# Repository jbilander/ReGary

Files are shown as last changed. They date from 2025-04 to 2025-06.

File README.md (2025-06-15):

# Fat ReGary
A drop in replacement PCB for the Fat Gary chip 

This is WORK IN PROGRESS. If you generate gerbers and order PCBs from this source you are doing so completely at your own risk!.

***

<a href="images/ReGary_pic1.jpg">
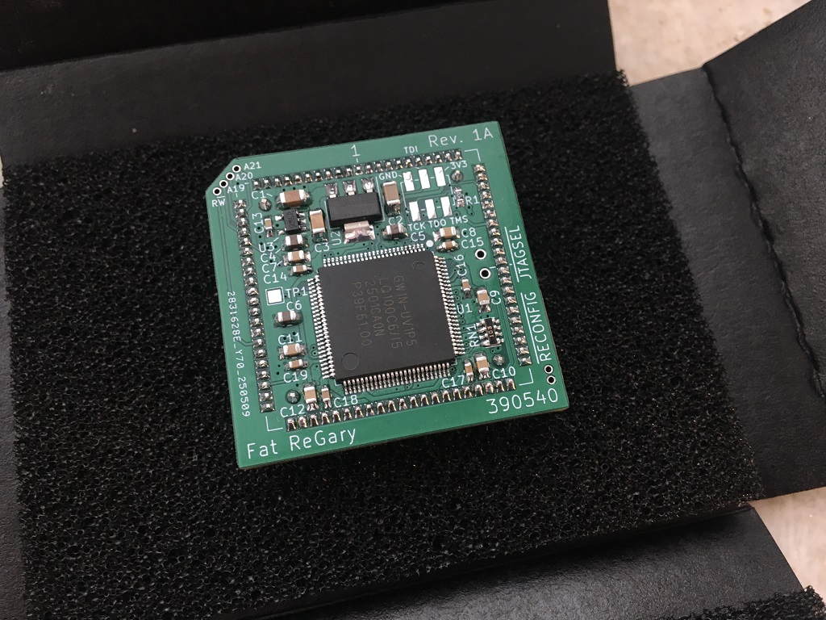
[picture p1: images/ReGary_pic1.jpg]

</a>
<a href="images/ReGary_pic2.jpg">
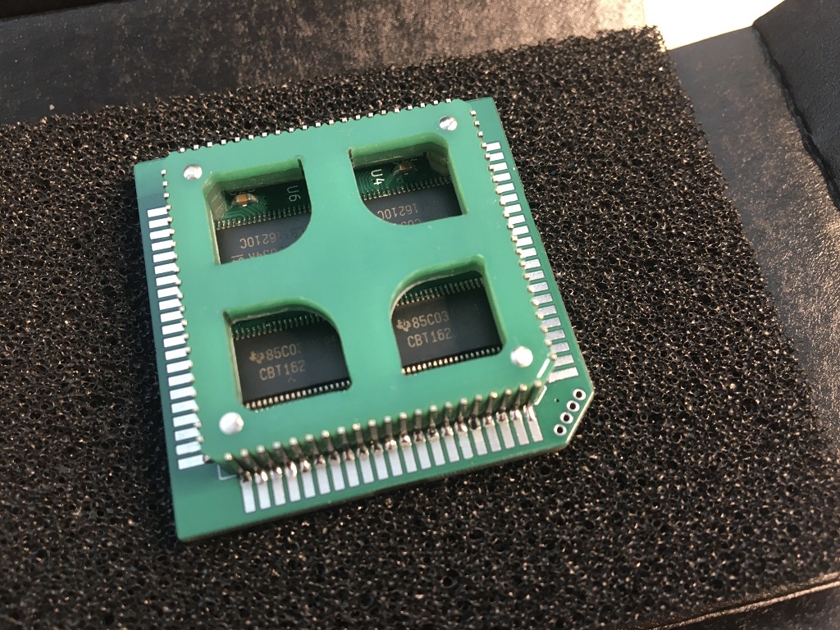
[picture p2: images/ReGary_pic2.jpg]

</a>
<a href="images/ReGary_pic3.jpg">
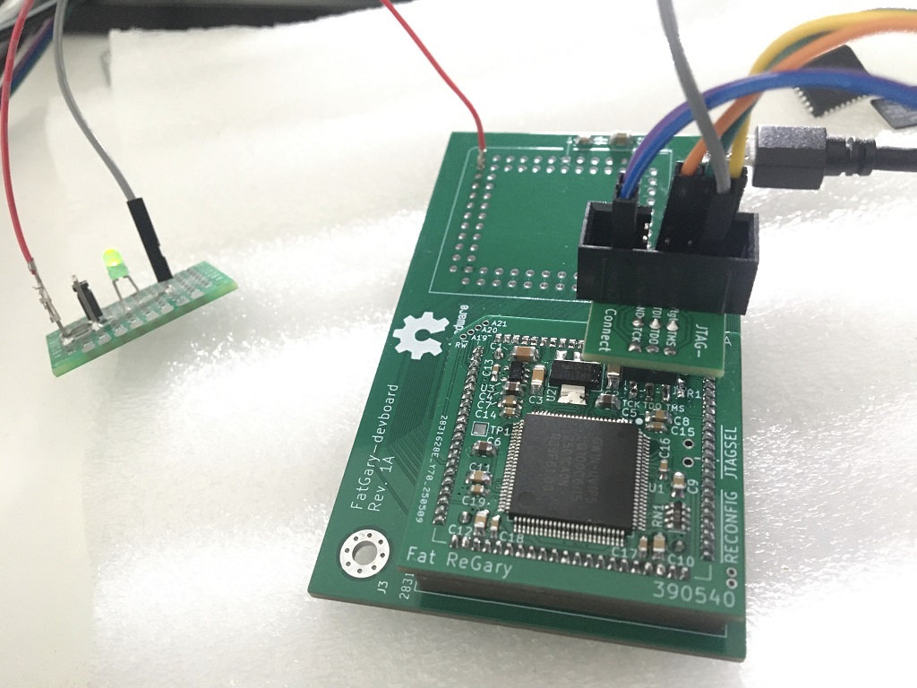
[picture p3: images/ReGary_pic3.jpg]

</a>

***

<a href="images/Fat_ReGary_pinmapping_rev1a.png">
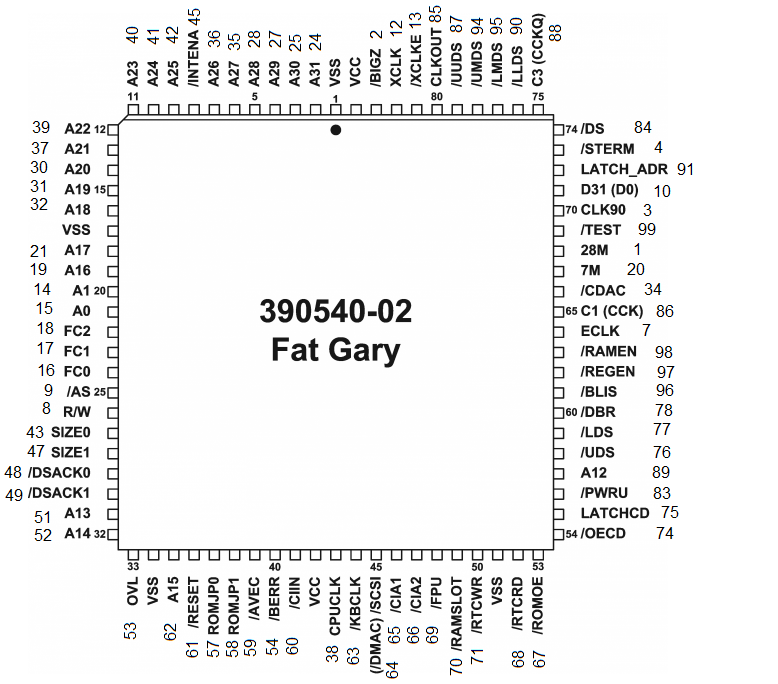
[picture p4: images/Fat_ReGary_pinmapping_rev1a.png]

</a>

***

BOM Rev. 1A
---------
Reference  | Name/Value   | Package | Notes
-|-|-|-|
U1 | GW1N-UV1P5LQ100  | TQFP-100_14x14mm_P0.5mm | Gowin FPGA [GW1N-UV1P5LQ100](https://www.mouser.com/ProductDetail/192-GW1P5LQ100C6-I5)
U2 | LM1117-3.3 | SOT-223 | Low-Dropout Linear Regulator 3.3 Volt
U3 | S-1132B43-M5T1U <br />or <br />TPS73643DBVR | SOT-23-5 | Low-Dropout Linear Regulator 4.3 Volt <br /> [S-1132B43-M5T1U](https://www.mouser.com/ProductDetail/628-S-1132B43-M5T1G) <br /> [TPS73643DBVR](https://www.mouser.com/ProductDetail/595-TPS73643DBVR) <br />
U4-U7 | SN74CBT16210 | TSSOP-48 6.1x12.5mm_P0.5mm | 20-BIT FET Bus switch with level shifting, high-speed TTL-compatible. [SN74CBT16210CDGGR ](https://www.mouser.com/ProductDetail/595-SN74CBT16210CDGG)
U8 | Winslow PLCC-84 Plug | PLCC-84 Plug | Optionally use a home made plug (stacked PCBs)
U9 | PLCC-84_TH_pin_holes | TH_plug_pins | Pins that could be used with the DIY-plug PCBs rev1d for manual fitting, L8.7mm [Aliexpress](https://www.aliexpress.com/item/32893608810.html).
R1 | 4.7k Ω | 0603 | Pull-down resistor for TCK (in JTAG)
RN1 | CAY16-103J4LF RES ARRAY 4 Resistors 10k Ω | 1206 | [CAY16-103J4LF](https://www.mouser.com/ProductDetail/652-CAY16-103J4LF)
C1-C3 | Capacitor 10uF | 1206 | 
C4-C6 | Capacitor 1uF | 0805 | 
C7-C12 | Capacitor 0.1uF = 100nF | 0805 | 
C13-C23 | Capacitor 0.01uF = 10nF | 0603 |
JTAG | SMT Pin Header Male | SMT 2 x 3 Pin 2.0mm pitch |

***

When ordering from JLCPCB select:

Specify Layer Sequence: Yes

    L1(Top layer):    F_Cu.gbr
    L2(Inner layer1): GND_Cu.gbr
    L3(Inner layer2): 4V3_Cu.gbr
    L4(Bottom layer): B_Cu.gbr

Remove Order Number: 

    Specify a location

This will notify JLC where to put the order number, they will replace the "JLCJLCJLCJLC" silkscreen label.

***

[][cc-by-sa]

This work is licensed under a
[Creative Commons Attribution-ShareAlike 4.0 International License][cc-by-sa].

[][cc-by-sa]

[cc-by-sa]: http://creativecommons.org/licenses/by-sa/4.0/
[cc-by-sa-image]: https://licensebuttons.net/l/by-sa/4.0/88x31.png
[cc-by-sa-shield]: https://img.shields.io/badge/License-CC%20BY--SA%204.0-lightgrey.svg

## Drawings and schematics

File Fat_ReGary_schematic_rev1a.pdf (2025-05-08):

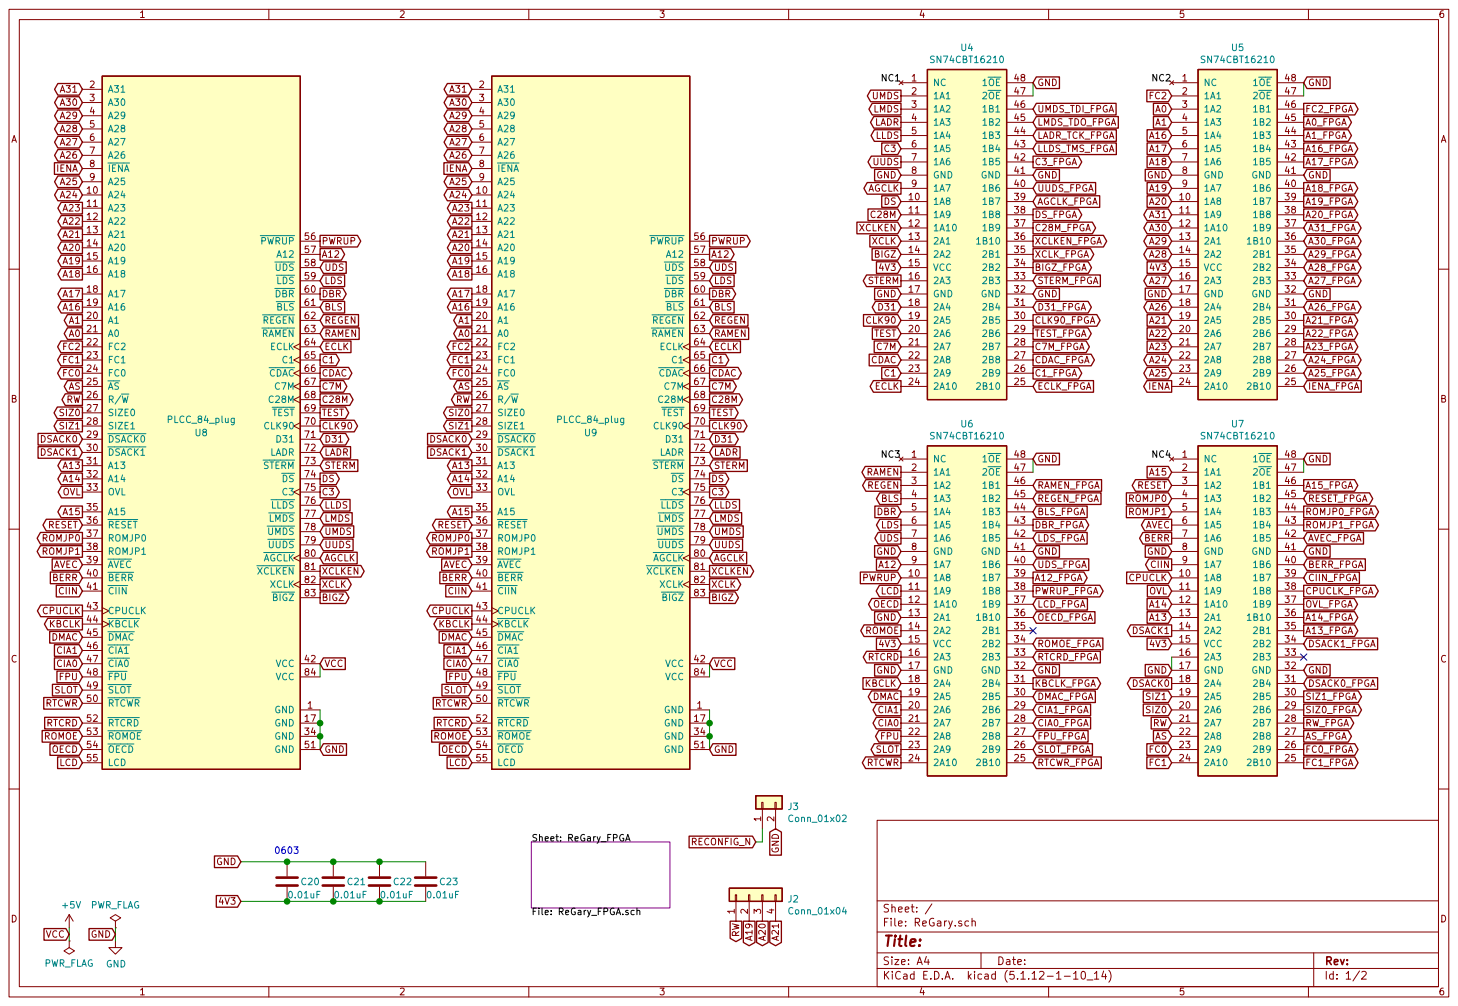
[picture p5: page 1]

File: ReGary.sch Sheet: / Sheet: ReGary_FPGA

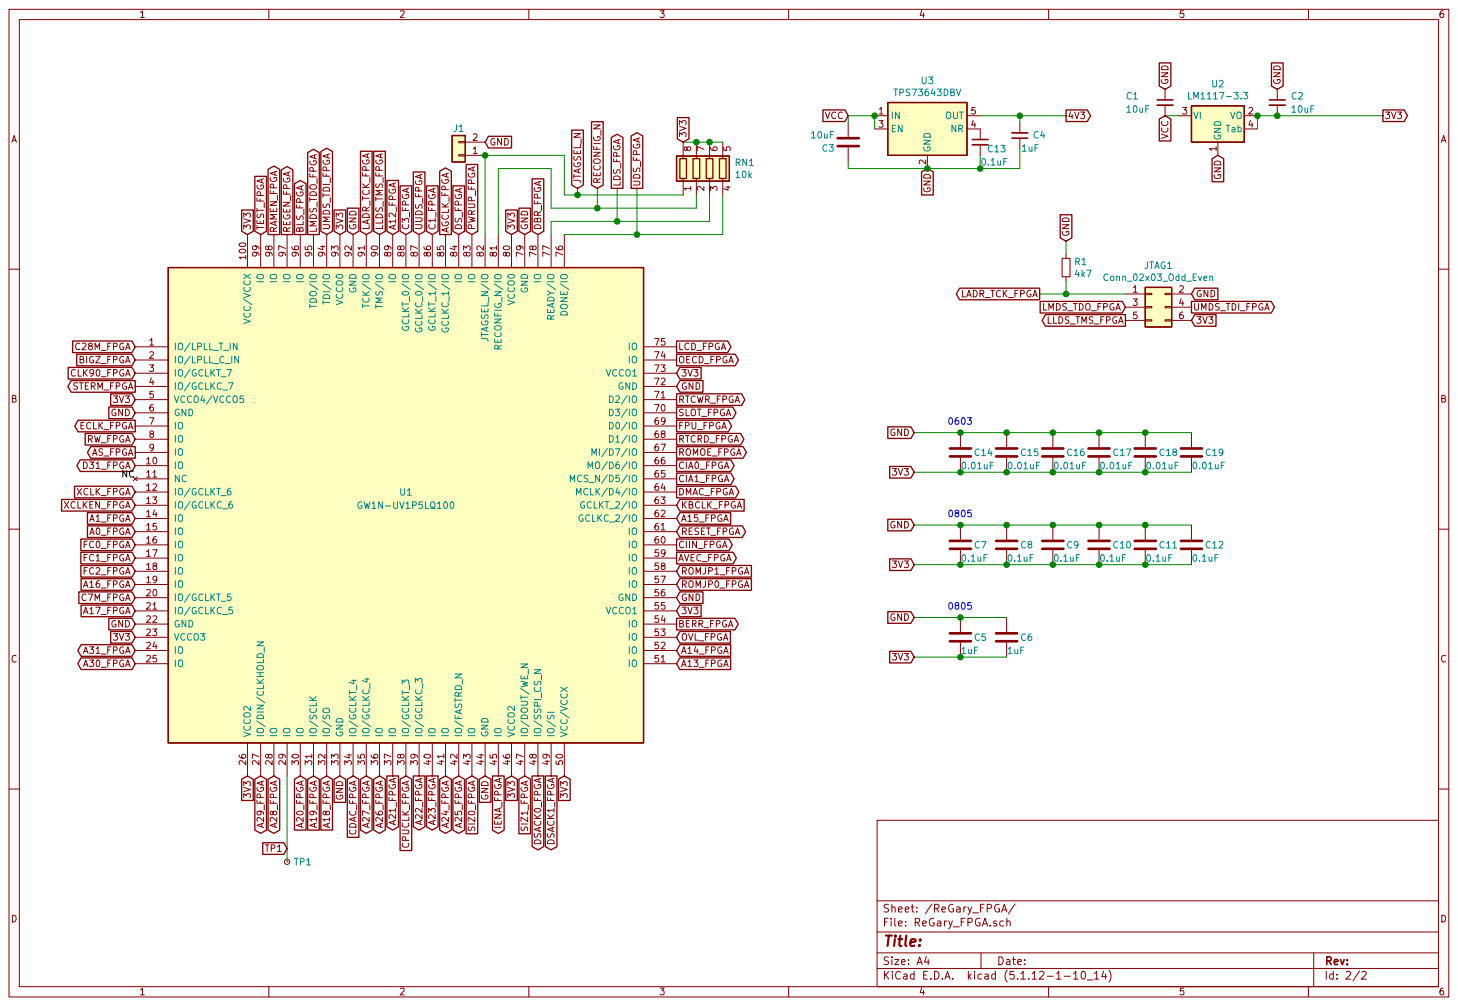
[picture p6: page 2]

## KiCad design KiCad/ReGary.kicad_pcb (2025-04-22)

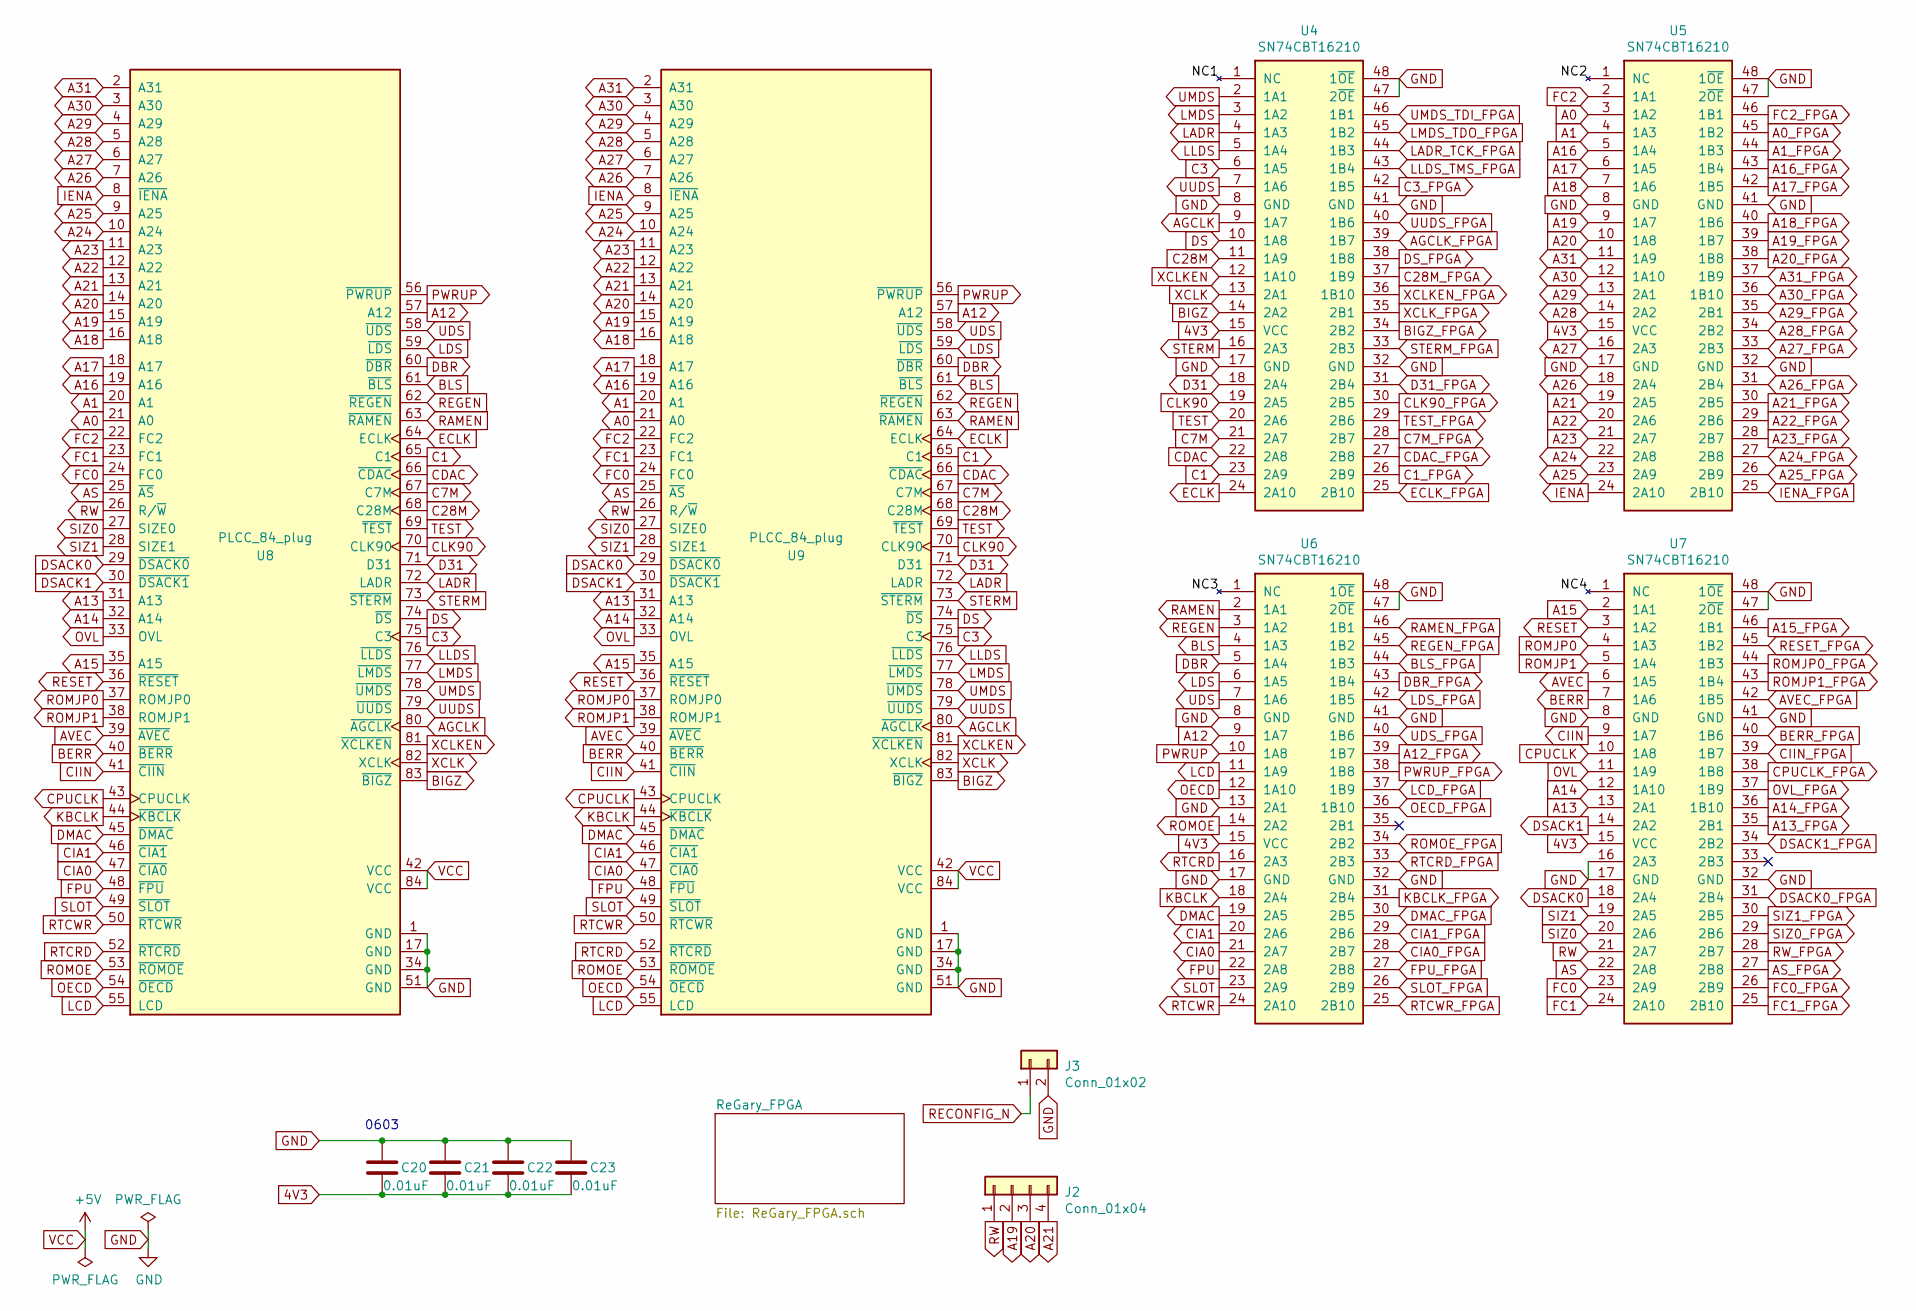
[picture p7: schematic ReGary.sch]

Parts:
C20, C21, C22, C23: 0.01uF; C_0603_1608Metric_Pad1.05x0.95mm_HandSolder
J2: Conn_01x04; PinHeader_1x04_P1.27mm_Vertical
J3: Conn_01x02; PinHeader_1x02_P1.27mm_Vertical
U4, U5, U6, U7: SN74CBT16210; TSSOP-48_6.1x12.5mm_P0.5mm_padLength_1mm
U8: PLCC_84_plug; PLCC-84_Plug_P1.27mm_mirrored
U9: PLCC_84_plug; PLCC-84_TH_pin_holes

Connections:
4V3: C20.2, C21.2, C22.2, C23.2, U4.15 (VCC), U5.15 (VCC), U6.15 (VCC), U7.15 (VCC); also elsewhere on the board
/NC1: U4.1 (NC)
/NC2: U5.1 (NC)
/NC3: U6.1 (NC)
/NC4: U7.1 (NC)
A0: U5.3 (1A2), U8.21 (A0), U9.21 (A0)
A0_FPGA: U5.45 (1B2); also elsewhere on the board
A1: U5.4 (1A3), U8.20 (A1), U9.20 (A1)
A1_FPGA: U5.44 (1B3); also elsewhere on the board
A12: U6.9 (1A7), U8.57 (A12), U9.57 (A12)
A12_FPGA: U6.39 (1B7); also elsewhere on the board
A13: U7.13 (2A1), U8.31 (A13), U9.31 (A13)
A13_FPGA: U7.35 (2B1); also elsewhere on the board
A14: U7.12 (1A10), U8.32 (A14), U9.32 (A14)
A14_FPGA: U7.36 (1B10); also elsewhere on the board
A15: U7.2 (1A1), U8.35 (A15), U9.35 (A15)
A15_FPGA: U7.46 (1B1); also elsewhere on the board
A16: U5.5 (1A4), U8.19 (A16), U9.19 (A16)
A16_FPGA: U5.43 (1B4); also elsewhere on the board
A17: U5.6 (1A5), U8.18 (A17), U9.18 (A17)
A17_FPGA: U5.42 (1B5); also elsewhere on the board
A18: U5.7 (1A6), U8.16 (A18), U9.16 (A18)
A18_FPGA: U5.40 (1B6); also elsewhere on the board
A19: J2.2, U5.9 (1A7), U8.15 (A19), U9.15 (A19)
A19_FPGA: U5.39 (1B7); also elsewhere on the board
A20: J2.3, U5.10 (1A8), U8.14 (A20), U9.14 (A20)
A20_FPGA: U5.38 (1B8); also elsewhere on the board
A21: J2.4, U5.19 (2A5), U8.13 (A21), U9.13 (A21)
A21_FPGA: U5.30 (2B5); also elsewhere on the board
A22: U5.20 (2A6), U8.12 (A22), U9.12 (A22)
A22_FPGA: U5.29 (2B6); also elsewhere on the board
A23: U5.21 (2A7), U8.11 (A23), U9.11 (A23)
A23_FPGA: U5.28 (2B7); also elsewhere on the board
A24: U5.22 (2A8), U8.10 (A24), U9.10 (A24)
A24_FPGA: U5.27 (2B8); also elsewhere on the board
A25: U5.23 (2A9), U8.9 (A25), U9.9 (A25)
A25_FPGA: U5.26 (2B9); also elsewhere on the board
A26: U5.18 (2A4), U8.7 (A26), U9.7 (A26)
A26_FPGA: U5.31 (2B4); also elsewhere on the board
A27: U5.16 (2A3), U8.6 (A27), U9.6 (A27)
A27_FPGA: U5.33 (2B3); also elsewhere on the board
A28: U5.14 (2A2), U8.5 (A28), U9.5 (A28)
A28_FPGA: U5.34 (2B2); also elsewhere on the board
A29: U5.13 (2A1), U8.4 (A29), U9.4 (A29)
A29_FPGA: U5.35 (2B1); also elsewhere on the board
A30: U5.12 (1A10), U8.3 (A30), U9.3 (A30)
A30_FPGA: U5.36 (1B10); also elsewhere on the board
A31: U5.11 (1A9), U8.2 (A31), U9.2 (A31)
A31_FPGA: U5.37 (1B9); also elsewhere on the board
AGCLK: U4.9 (1A7), U8.80 (~AGCLK), U9.80 (~AGCLK)
AGCLK_FPGA: U4.39 (1B7); also elsewhere on the board
AS: U7.22 (2A8), U8.25 (~AS), U9.25 (~AS)
AS_FPGA: U7.27 (2B8); also elsewhere on the board
AVEC: U7.6 (1A5), U8.39 (~AVEC), U9.39 (~AVEC)
AVEC_FPGA: U7.42 (1B5); also elsewhere on the board
BERR: U7.7 (1A6), U8.40 (~BERR), U9.40 (~BERR)
BERR_FPGA: U7.40 (1B6); also elsewhere on the board
BIGZ: U4.14 (2A2), U8.83 (~BIGZ), U9.83 (~BIGZ)
BIGZ_FPGA: U4.34 (2B2); also elsewhere on the board
BLS: U6.4 (1A3), U8.61 (~BLS), U9.61 (~BLS)
BLS_FPGA: U6.44 (1B3); also elsewhere on the board
C1: U4.23 (2A9), U8.65 (C1), U9.65 (C1)
C1_FPGA: U4.26 (2B9); also elsewhere on the board
C3: U4.6 (1A5), U8.75 (C3), U9.75 (C3)
C3_FPGA: U4.42 (1B5); also elsewhere on the board
C7M: U4.21 (2A7), U8.67 (C7M), U9.67 (C7M)
C7M_FPGA: U4.28 (2B7); also elsewhere on the board
C28M: U4.11 (1A9), U8.68 (C28M), U9.68 (C28M)
C28M_FPGA: U4.37 (1B9); also elsewhere on the board
CDAC: U4.22 (2A8), U8.66 (~CDAC), U9.66 (~CDAC)
CDAC_FPGA: U4.27 (2B8); also elsewhere on the board
CIA0: U6.21 (2A7), U8.47 (~CIA0), U9.47 (~CIA0)
CIA0_FPGA: U6.28 (2B7); also elsewhere on the board
CIA1: U6.20 (2A6), U8.46 (~CIA1), U9.46 (~CIA1)
CIA1_FPGA: U6.29 (2B6); also elsewhere on the board
CIIN: U7.9 (1A7), U8.41 (~CIIN), U9.41 (~CIIN)
CIIN_FPGA: U7.39 (1B7); also elsewhere on the board
CLK90: U4.19 (2A5), U8.70 (CLK90), U9.70 (CLK90)
CLK90_FPGA: U4.30 (2B5); also elsewhere on the board
CPUCLK: U7.10 (1A8), U8.43 (CPUCLK), U9.43 (CPUCLK)
CPUCLK_FPGA: U7.38 (1B8); also elsewhere on the board
D31: U4.18 (2A4), U8.71 (D31), U9.71 (D31)
D31_FPGA: U4.31 (2B4); also elsewhere on the board
DBR: U6.5 (1A4), U8.60 (~DBR), U9.60 (~DBR)
DBR_FPGA: U6.43 (1B4); also elsewhere on the board
DMAC: U6.19 (2A5), U8.45 (~DMAC), U9.45 (~DMAC)
DMAC_FPGA: U6.30 (2B5); also elsewhere on the board
DS: U4.10 (1A8), U8.74 (~DS), U9.74 (~DS)
DSACK0: U7.18 (2A4), U8.29 (~DSACK0), U9.29 (~DSACK0)
DSACK0_FPGA: U7.31 (2B4); also elsewhere on the board
DSACK1: U7.14 (2A2), U8.30 (~DSACK1), U9.30 (~DSACK1)
DSACK1_FPGA: U7.34 (2B2); also elsewhere on the board
DS_FPGA: U4.38 (1B8); also elsewhere on the board
ECLK: U4.24 (2A10), U8.64 (ECLK), U9.64 (ECLK)
ECLK_FPGA: U4.25 (2B10); also elsewhere on the board
FC0: U7.23 (2A9), U8.24 (FC0), U9.24 (FC0)
FC0_FPGA: U7.26 (2B9); also elsewhere on the board
FC1: U7.24 (2A10), U8.23 (FC1), U9.23 (FC1)
FC1_FPGA: U7.25 (2B10); also elsewhere on the board
FC2: U5.2 (1A1), U8.22 (FC2), U9.22 (FC2)
FC2_FPGA: U5.46 (1B1); also elsewhere on the board
FPU: U6.22 (2A8), U8.48 (~FPU), U9.48 (~FPU)
FPU_FPGA: U6.27 (2B8); also elsewhere on the board
GND: C20.1, C21.1, C22.1, C23.1, J3.2, U4.8 (GND), U4.17 (GND), U4.32 (GND), U4.41 (GND), U4.47 (2~OE), U4.48 (1~OE), U5.8 (GND), U5.17 (GND), U5.32 (GND), U5.41 (GND), U5.47 (2~OE), U5.48 (1~OE), U6.8 (GND), U6.13 (2A1), U6.17 (GND), U6.32 (GND), U6.41 (GND), U6.47 (2~OE), U6.48 (1~OE), U7.8 (GND), U7.16 (2A3), U7.17 (GND), U7.32 (GND), U7.41 (GND), U7.47 (2~OE), U7.48 (1~OE), U8.1 (GND), U8.17 (GND), U8.34 (GND), U8.51 (GND), U9.1 (GND), U9.17 (GND), U9.34 (GND), U9.51 (GND); also elsewhere on the board
IENA: U5.24 (2A10), U8.8 (~IENA), U9.8 (~IENA)
IENA_FPGA: U5.25 (2B10); also elsewhere on the board
KBCLK: U6.18 (2A4), U8.44 (~KBCLK), U9.44 (~KBCLK)
KBCLK_FPGA: U6.31 (2B4); also elsewhere on the board
LADR: U4.4 (1A3), U8.72 (LADR), U9.72 (LADR)
LADR_TCK_FPGA: U4.44 (1B3); also elsewhere on the board
LCD: U6.11 (1A9), U8.55 (LCD), U9.55 (LCD)
LCD_FPGA: U6.37 (1B9); also elsewhere on the board
LDS: U6.6 (1A5), U8.59 (~LDS), U9.59 (~LDS)
LDS_FPGA: U6.42 (1B5); also elsewhere on the board
LLDS: U4.5 (1A4), U8.76 (~LLDS), U9.76 (~LLDS)
LLDS_TMS_FPGA: U4.43 (1B4); also elsewhere on the board
LMDS: U4.3 (1A2), U8.77 (~LMDS), U9.77 (~LMDS)
LMDS_TDO_FPGA: U4.45 (1B2); also elsewhere on the board
OECD: U6.12 (1A10), U8.54 (~OECD), U9.54 (~OECD)
OECD_FPGA: U6.36 (1B10); also elsewhere on the board
OVL: U7.11 (1A9), U8.33 (OVL), U9.33 (OVL)
OVL_FPGA: U7.37 (1B9); also elsewhere on the board
PWRUP: U6.10 (1A8), U8.56 (~PWRUP), U9.56 (~PWRUP)
PWRUP_FPGA: U6.38 (1B8); also elsewhere on the board
RAMEN: U6.2 (1A1), U8.63 (~RAMEN), U9.63 (~RAMEN)
RAMEN_FPGA: U6.46 (1B1); also elsewhere on the board
RECONFIG_N: J3.1; also elsewhere on the board
REGEN: U6.3 (1A2), U8.62 (~REGEN), U9.62 (~REGEN)
REGEN_FPGA: U6.45 (1B2); also elsewhere on the board
RESET: U7.3 (1A2), U8.36 (~RESET), U9.36 (~RESET)
RESET_FPGA: U7.45 (1B2); also elsewhere on the board
ROMJP0: U7.4 (1A3), U8.37 (ROMJP0), U9.37 (ROMJP0)
ROMJP0_FPGA: U7.44 (1B3); also elsewhere on the board
ROMJP1: U7.5 (1A4), U8.38 (ROMJP1), U9.38 (ROMJP1)
ROMJP1_FPGA: U7.43 (1B4); also elsewhere on the board
ROMOE: U6.14 (2A2), U8.53 (~ROMOE), U9.53 (~ROMOE)
ROMOE_FPGA: U6.34 (2B2); also elsewhere on the board
RTCRD: U6.16 (2A3), U8.52 (~RTCRD), U9.52 (~RTCRD)
RTCRD_FPGA: U6.33 (2B3); also elsewhere on the board
RTCWR: U6.24 (2A10), U8.50 (~RTCWR), U9.50 (~RTCWR)
RTCWR_FPGA: U6.25 (2B10); also elsewhere on the board
RW: J2.1, U7.21 (2A7), U8.26 (R/~W), U9.26 (R/~W)
RW_FPGA: U7.28 (2B7); also elsewhere on the board
SIZ0: U7.20 (2A6), U8.27 (SIZE0), U9.27 (SIZE0)
SIZ0_FPGA: U7.29 (2B6); also elsewhere on the board
SIZ1: U7.19 (2A5), U8.28 (SIZE1), U9.28 (SIZE1)
SIZ1_FPGA: U7.30 (2B5); also elsewhere on the board
SLOT: U6.23 (2A9), U8.49 (~SLOT), U9.49 (~SLOT)
SLOT_FPGA: U6.26 (2B9); also elsewhere on the board
STERM: U4.16 (2A3), U8.73 (~STERM), U9.73 (~STERM)
STERM_FPGA: U4.33 (2B3); also elsewhere on the board
TEST: U4.20 (2A6), U8.69 (~TEST), U9.69 (~TEST)
TEST_FPGA: U4.29 (2B6); also elsewhere on the board
UDS: U6.7 (1A6), U8.58 (~UDS), U9.58 (~UDS)
UDS_FPGA: U6.40 (1B6); also elsewhere on the board
UMDS: U4.2 (1A1), U8.78 (~UMDS), U9.78 (~UMDS)
UMDS_TDI_FPGA: U4.46 (1B1); also elsewhere on the board
UUDS: U4.7 (1A6), U8.79 (~UUDS), U9.79 (~UUDS)
UUDS_FPGA: U4.40 (1B6); also elsewhere on the board
VCC: U8.42 (VCC), U8.84 (VCC), U9.42 (VCC), U9.84 (VCC); also elsewhere on the board
XCLK: U4.13 (2A1), U8.82 (XCLK), U9.82 (XCLK)
XCLKEN: U4.12 (1A10), U8.81 (~XCLKEN), U9.81 (~XCLKEN)
XCLKEN_FPGA: U4.36 (1B10); also elsewhere on the board
XCLK_FPGA: U4.35 (2B1); also elsewhere on the board

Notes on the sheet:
0603

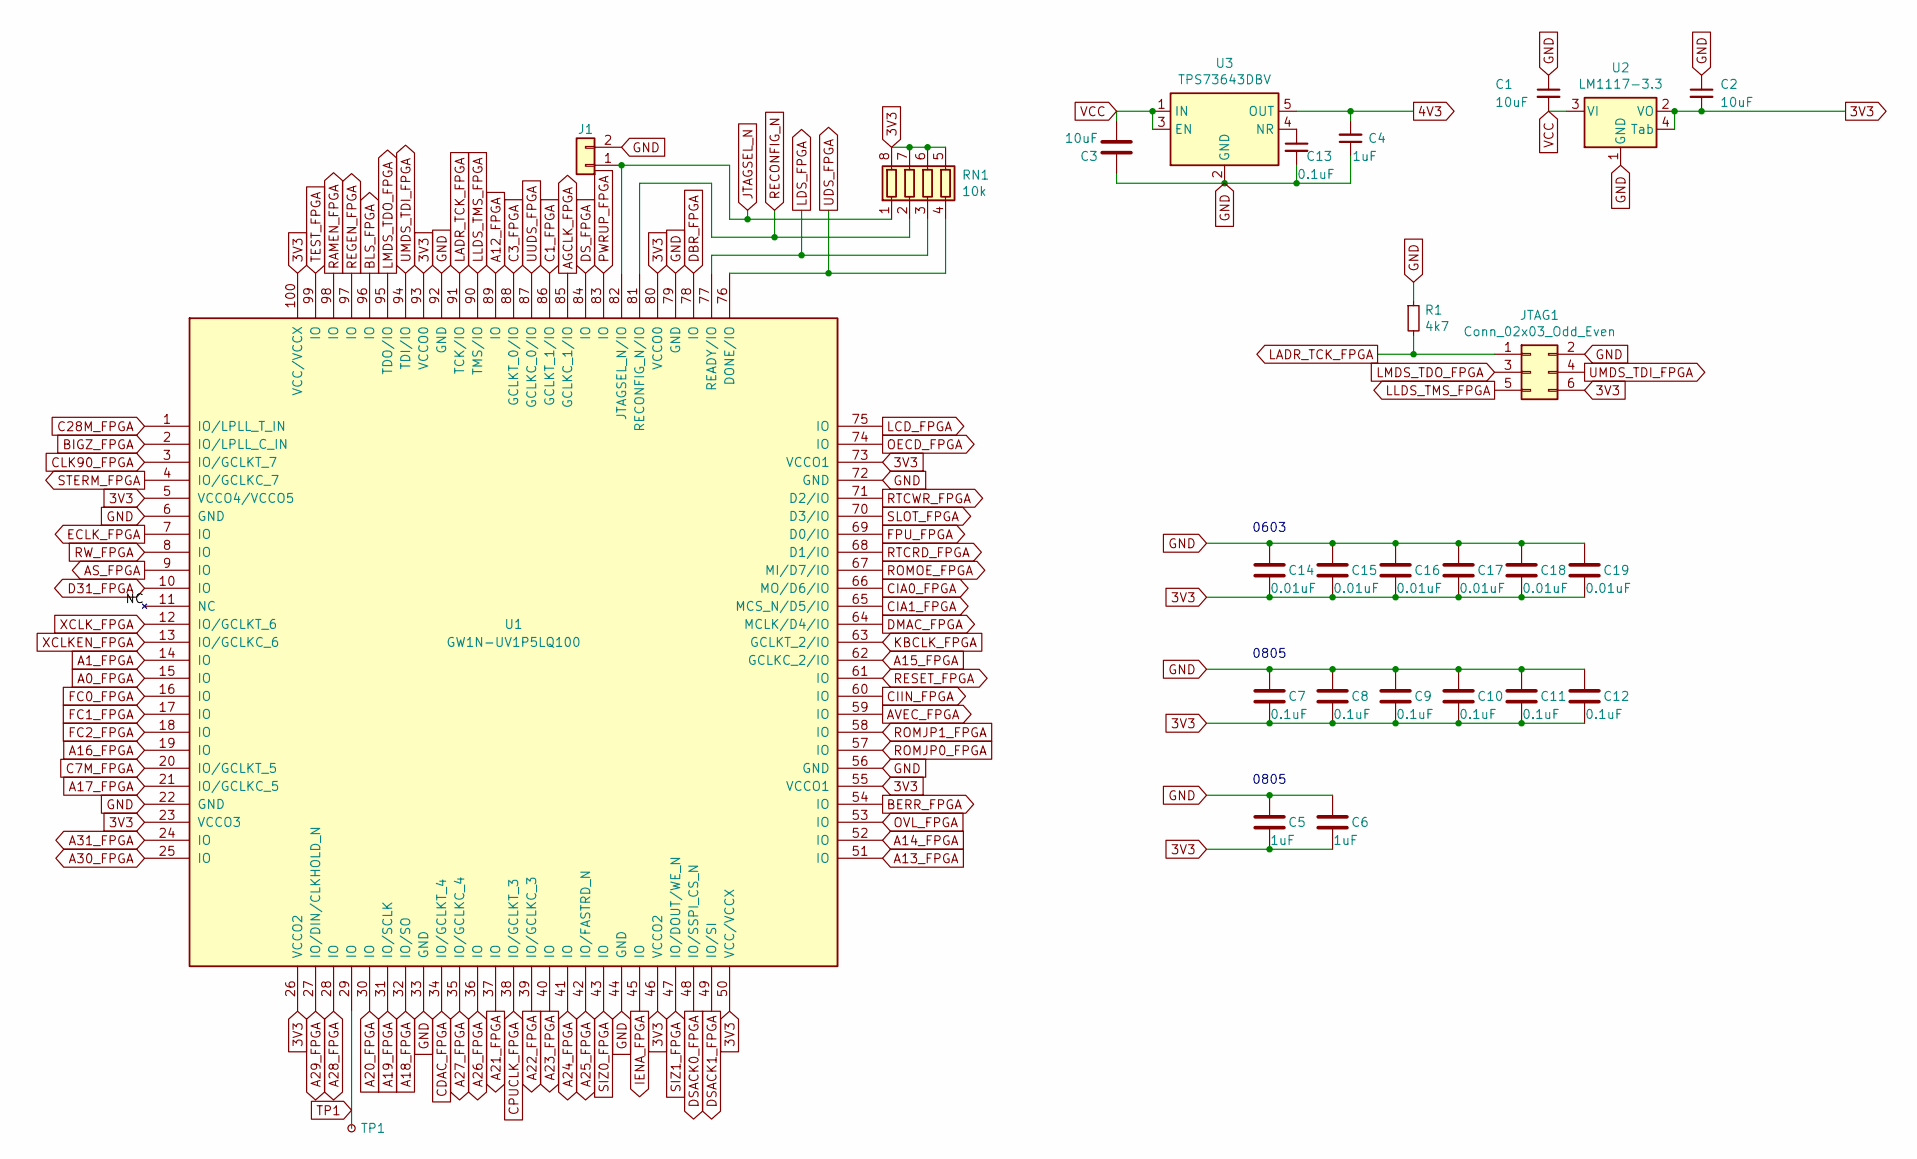
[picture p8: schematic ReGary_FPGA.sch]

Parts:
C1, C2, C3: 10uF; C_1206_3216Metric_Pad1.42x1.75mm_HandSolder
C4: 1uF; C_0805_2012Metric_Pad1.15x1.40mm_HandSolder
C5, C6: 1uF; C_0805_2012Metric_Pad1.18x1.45mm_HandSolder
C7, C8, C9, C10, C11, C12: 0.1uF; C_0805_2012Metric_Pad1.18x1.45mm_HandSolder
C13: 0.1uF; C_0603_1608Metric_Pad1.08x0.95mm_HandSolder
C14, C15, C16, C17, C18, C19: 0.01uF; C_0603_1608Metric_Pad1.08x0.95mm_HandSolder
J1: Conn_01x02; PinHeader_1x02_P2.54mm_Vertical
JTAG1: Conn_02x03_Odd_Even; PinHeader_2x03_P2.00mm_Vertical_SMD
R1: 4k7; R_0603_1608Metric_Pad0.98x0.95mm_HandSolder
RN1: 10k; RESCAF80P320X160X60-8N
TP1: TestPoint_Small; TestPoint_Pad_1.5x1.5mm
U1: GW1N-UV1P5LQ100; TQFP-100_14x14mm_P0.5mm
U2: LM1117-3.3; SOT-223
U3: TPS73643DBV; SOT-23-5

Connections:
3V3: C2.2, C5.2, C6.2, C7.2, C8.2, C9.2, C10.2, C11.2, C12.2, C14.2, C15.2, C16.2, C17.2, C18.2, C19.2, JTAG1.6, RN1.5 (R4.2), RN1.6 (R3.2), RN1.7 (R2.2), RN1.8 (R1.2), U1.5 (VCCO4/VCCO5), U1.23 (VCCO3), U1.26 (VCCO2), U1.46 (VCCO2), U1.50 (VCC/VCCX), U1.55 (VCCO1), U1.73 (VCCO1), U1.80 (VCCO0), U1.93 (VCCO0), U1.100 (VCC/VCCX), U2.2 (VO), U2.4 (Tab)
4V3: C4.2, U3.5 (OUT); also elsewhere on the board
/ReGary_FPGA/NC: U1.11 (NC)
A0_FPGA: U1.15 (IO); also elsewhere on the board
A1_FPGA: U1.14 (IO); also elsewhere on the board
A12_FPGA: U1.89 (IO); also elsewhere on the board
A13_FPGA: U1.51 (IO); also elsewhere on the board
A14_FPGA: U1.52 (IO); also elsewhere on the board
A15_FPGA: U1.62 (GCLKC_2/IO); also elsewhere on the board
A16_FPGA: U1.19 (IO); also elsewhere on the board
A17_FPGA: U1.21 (IO/GCLKC_5); also elsewhere on the board
A18_FPGA: U1.32 (IO/SO); also elsewhere on the board
A19_FPGA: U1.31 (IO/SCLK); also elsewhere on the board
A20_FPGA: U1.30 (IO); also elsewhere on the board
A21_FPGA: U1.37 (IO); also elsewhere on the board
A22_FPGA: U1.39 (IO/GCLKC_3); also elsewhere on the board
A23_FPGA: U1.40 (IO); also elsewhere on the board
A24_FPGA: U1.41 (IO); also elsewhere on the board
A25_FPGA: U1.42 (IO/FASTRD_N); also elsewhere on the board
A26_FPGA: U1.36 (IO); also elsewhere on the board
A27_FPGA: U1.35 (IO/GCLKC_4); also elsewhere on the board
A28_FPGA: U1.28 (IO); also elsewhere on the board
A29_FPGA: U1.27 (IO/DIN/CLKHOLD_N); also elsewhere on the board
A30_FPGA: U1.25 (IO); also elsewhere on the board
A31_FPGA: U1.24 (IO); also elsewhere on the board
AGCLK_FPGA: U1.85 (GCLKC_1/IO); also elsewhere on the board
AS_FPGA: U1.9 (IO); also elsewhere on the board
AVEC_FPGA: U1.59 (IO); also elsewhere on the board
BERR_FPGA: U1.54 (IO); also elsewhere on the board
BIGZ_FPGA: U1.2 (IO/LPLL_C_IN); also elsewhere on the board
BLS_FPGA: U1.96 (IO); also elsewhere on the board
C1_FPGA: U1.86 (GCLKT_1/IO); also elsewhere on the board
C3_FPGA: U1.88 (GCLKT_0/IO); also elsewhere on the board
C7M_FPGA: U1.20 (IO/GCLKT_5); also elsewhere on the board
C28M_FPGA: U1.1 (IO/LPLL_T_IN); also elsewhere on the board
CDAC_FPGA: U1.34 (IO/GCLKT_4); also elsewhere on the board
CIA0_FPGA: U1.66 (MO/D6/IO); also elsewhere on the board
CIA1_FPGA: U1.65 (MCS_N/D5/IO); also elsewhere on the board
CIIN_FPGA: U1.60 (IO); also elsewhere on the board
CLK90_FPGA: U1.3 (IO/GCLKT_7); also elsewhere on the board
CPUCLK_FPGA: U1.38 (IO/GCLKT_3); also elsewhere on the board
D31_FPGA: U1.10 (IO); also elsewhere on the board
DBR_FPGA: U1.78 (IO); also elsewhere on the board
DMAC_FPGA: U1.64 (MCLK/D4/IO); also elsewhere on the board
DSACK0_FPGA: U1.48 (IO/SSPI_CS_N); also elsewhere on the board
DSACK1_FPGA: U1.49 (IO/SI); also elsewhere on the board
DS_FPGA: U1.84 (IO); also elsewhere on the board
ECLK_FPGA: U1.7 (IO); also elsewhere on the board
FC0_FPGA: U1.16 (IO); also elsewhere on the board
FC1_FPGA: U1.17 (IO); also elsewhere on the board
FC2_FPGA: U1.18 (IO); also elsewhere on the board
FPU_FPGA: U1.69 (D0/IO); also elsewhere on the board
GND: C1.1, C2.1, C3.1, C4.1, C5.1, C6.1, C7.1, C8.1, C9.1, C10.1, C11.1, C12.1, C13.2, C14.1, C15.1, C16.1, C17.1, C18.1, C19.1, J1.2, JTAG1.2, R1.1, U1.6 (GND), U1.22 (GND), U1.33 (GND), U1.44 (GND), U1.56 (GND), U1.72 (GND), U1.79 (GND), U1.92 (GND), U2.1 (GND), U3.2 (GND); also elsewhere on the board
IENA_FPGA: U1.45 (IO); also elsewhere on the board
JTAGSEL_N: J1.1, RN1.1 (R1.1), U1.82 (JTAGSEL_N/IO)
KBCLK_FPGA: U1.63 (GCLKT_2/IO); also elsewhere on the board
LADR_TCK_FPGA: JTAG1.1, R1.2, U1.91 (TCK/IO); also elsewhere on the board
LCD_FPGA: U1.75 (IO); also elsewhere on the board
LDS_FPGA: RN1.3 (R3.1), U1.77 (READY/IO); also elsewhere on the board
LLDS_TMS_FPGA: JTAG1.5, U1.90 (TMS/IO); also elsewhere on the board
LMDS_TDO_FPGA: JTAG1.3, U1.95 (TDO/IO); also elsewhere on the board
unnamed: C13.1, U3.4 (NR)
OECD_FPGA: U1.74 (IO); also elsewhere on the board
OVL_FPGA: U1.53 (IO); also elsewhere on the board
PWRUP_FPGA: U1.83 (IO); also elsewhere on the board
RAMEN_FPGA: U1.98 (IO); also elsewhere on the board
RECONFIG_N: RN1.2 (R2.1), U1.81 (RECONFIG_N/IO); also elsewhere on the board
REGEN_FPGA: U1.97 (IO); also elsewhere on the board
RESET_FPGA: U1.61 (IO); also elsewhere on the board
ROMJP0_FPGA: U1.57 (IO); also elsewhere on the board
ROMJP1_FPGA: U1.58 (IO); also elsewhere on the board
ROMOE_FPGA: U1.67 (MI/D7/IO); also elsewhere on the board
RTCRD_FPGA: U1.68 (D1/IO); also elsewhere on the board
RTCWR_FPGA: U1.71 (D2/IO); also elsewhere on the board
RW_FPGA: U1.8 (IO); also elsewhere on the board
SIZ0_FPGA: U1.43 (IO); also elsewhere on the board
SIZ1_FPGA: U1.47 (IO/DOUT/WE_N); also elsewhere on the board
SLOT_FPGA: U1.70 (D3/IO); also elsewhere on the board
STERM_FPGA: U1.4 (IO/GCLKC_7); also elsewhere on the board
TEST_FPGA: U1.99 (IO); also elsewhere on the board
TP1: TP1.1, U1.29 (IO)
UDS_FPGA: RN1.4 (R4.1), U1.76 (DONE/IO); also elsewhere on the board
UMDS_TDI_FPGA: JTAG1.4, U1.94 (TDI/IO); also elsewhere on the board
UUDS_FPGA: U1.87 (GCLKC_0/IO); also elsewhere on the board
VCC: C1.2, C3.2, U2.3 (VI), U3.1 (IN), U3.3 (EN); also elsewhere on the board
XCLKEN_FPGA: U1.13 (IO/GCLKC_6); also elsewhere on the board
XCLK_FPGA: U1.12 (IO/GCLKT_6); also elsewhere on the board

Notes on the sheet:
0603
0805

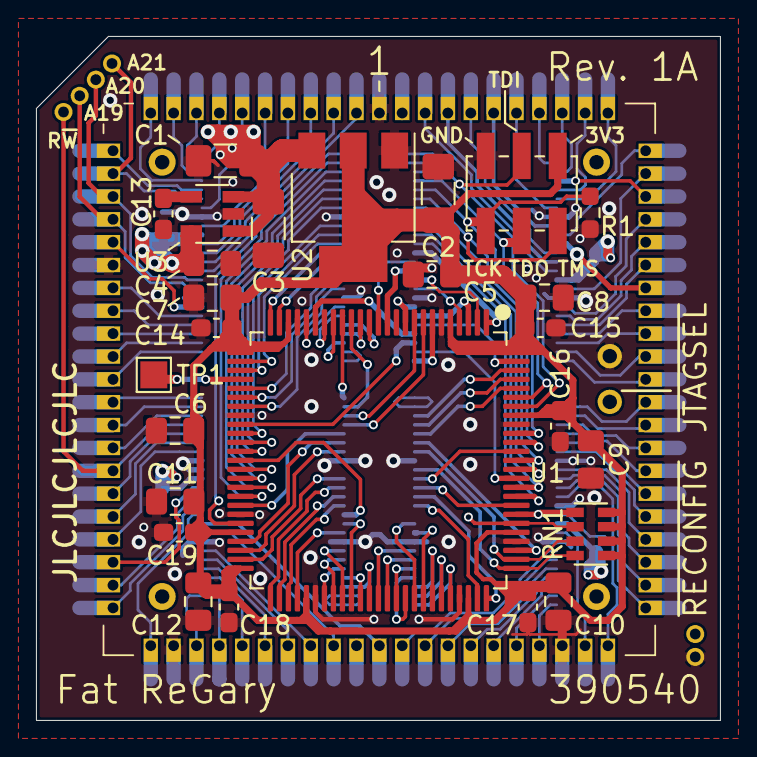
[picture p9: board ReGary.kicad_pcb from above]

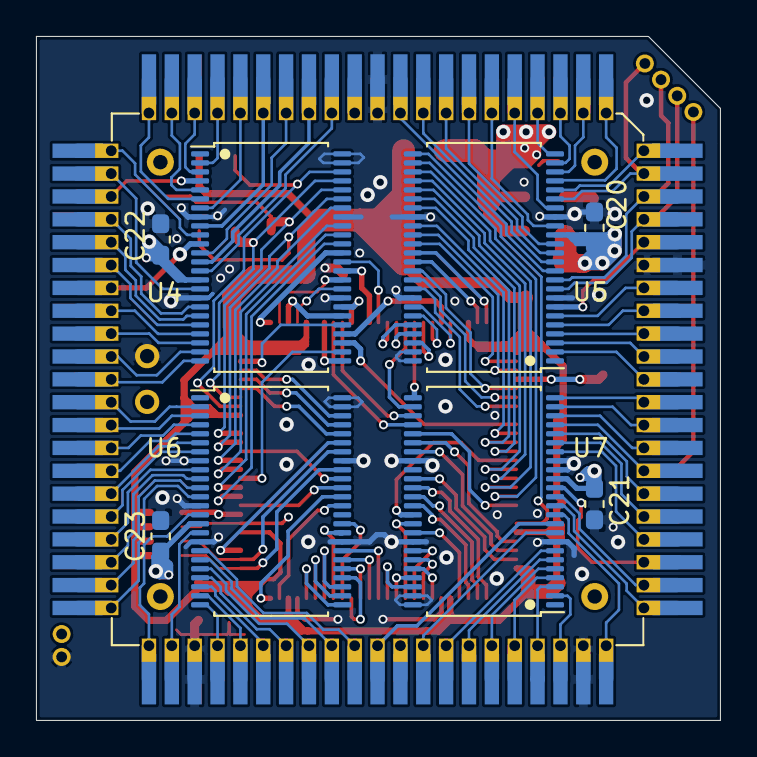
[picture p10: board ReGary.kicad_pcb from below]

Board: 4 copper layers, 38.0 x 38.0 mm, 39 parts (9 on the bottom side), 164 nets.

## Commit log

2025-02-12 Add footprints
2025-02-12 Add KiCad files
    [ReGary.kicad_pcb, ReGary.sch, ReGary_FPGA.sch]
2025-02-12 Add Fat Gary socket symbol and change to it
    [ReGary.kicad_pcb, ReGary.sch]
2025-02-12 Removed BGA FPGA
    [ReGary.kicad_pcb, ReGary.sch, ReGary_FPGA.sch]
2025-02-12 Add Gowin FPGA GW1N-UV1P5LQ100 into the design
    [ReGary.kicad_pcb, ReGary_FPGA.sch]
2025-02-12 Add footprint
2025-02-13 Change to 6-pin JTAG-header
    [ReGary.kicad_pcb, ReGary_FPGA.sch]
2025-02-13 Fix placement of VCC vias, C1 and U2 voltage regulator
    [ReGary.kicad_pcb]
2025-02-13 Add a 4V3 LDO voltage regulator
    [ReGary.kicad_pcb, ReGary_FPGA.sch]
2025-02-14 Change level shifters from CBTD to CBT with 4V3 power supply, change inner power layer from VCC to 4V3
    [ReGary.kicad_pcb, ReGary.sch]
2025-02-14 Fixed placement of C5 and FPGA, more cleanup of old vias and traces
    [ReGary.kicad_pcb, ReGary_FPGA.sch]
2025-02-14 fixed placement of capacitors C8 and C9
    [ReGary.kicad_pcb, ReGary.sch, ReGary_FPGA.sch]
2025-02-15 Add JTAG routing and 4.7k pull-down resistor on TCK-line
    [ReGary.kicad_pcb, ReGary_FPGA.sch]
2025-02-15 fixed placement of capacitors C9,C10 and resistor array RN1
    [ReGary.kicad_pcb, ReGary_FPGA.sch]
2025-02-15 Add JP header for JTAGSEL_N, fixed JTAG as dual-purpose pins
    [ReGary.kicad_pcb, ReGary.sch, ReGary_FPGA.sch]
2025-02-16 Removed the 0.45 mm / 0.2 mm via option
2025-02-16 More signal to pin assignments and routing
    [ReGary.kicad_pcb, ReGary.sch, ReGary_FPGA.sch]
2025-02-16 More FPGA pin assignments and routing
    [ReGary.kicad_pcb, ReGary.sch, ReGary_FPGA.sch]
2025-02-17 Placement of caps and more routing
    [ReGary.kicad_pcb, ReGary.sch, ReGary_FPGA.sch]
2025-02-18 More signal to pin assignments and routing done, moved /REGEN and /RAMEN signals to FPGA pin 97,98
    [ReGary.kicad_pcb, ReGary_FPGA.sch]
2025-02-18 More pin assignments and routing
    [ReGary.kicad_pcb, ReGary.sch, ReGary_FPGA.sch]
2025-02-18 Placement of caps and more routing of 3V3-power
    [ReGary.kicad_pcb, ReGary_FPGA.sch]
2025-02-20 More signals to pin assignments and more routing done
    [ReGary.kicad_pcb, ReGary.sch, ReGary_FPGA.sch]
2025-02-20 Improved GND by adding/relocating some GND-vias, also more routing fixes done
    [ReGary.kicad_pcb]
2025-02-20 Fixed enumeration of capacitors and placement of last capacitor C11 for 3V3-power
    [ReGary.kicad_pcb, ReGary.sch, ReGary_FPGA.sch]
2025-02-20 Fixed JTAGSEL_N header size and silkscreen placement
    [ReGary.kicad_pcb, ReGary.sch, ReGary_FPGA.sch]
2025-02-20 silkscreen fixes on front side
    [ReGary.kicad_pcb]
2025-02-21 silkscreen fixes on the underside
    [ReGary.kicad_pcb]
2025-03-02 Add a pin-header (with RW, A21, A20, A19 signals) for a built in Romy
    [ReGary.kicad_pcb, ReGary.sch]
2025-04-22 Add 1.27 mm pitch pin-header for RECONFIG_N signal
    [ReGary.kicad_pcb, ReGary.sch]
2025-05-08 Add schematic pdf

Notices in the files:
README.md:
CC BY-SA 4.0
